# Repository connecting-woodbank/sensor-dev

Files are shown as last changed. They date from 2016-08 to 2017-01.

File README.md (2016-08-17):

README
======
The Connecting Woodbank project aims to create a wireless sensor network for monitoring growing conditions to reduce inefficiencies within small-scale agriculture.  It is comprised of a network of sensor nodes based around an Arduino board conected to a series of sensors and a short range radio.

Sensors
=======
The sensor nodes each contain sensors for measuring:
- soil temperature
- soil relative moisture
- air temperatue
- air relative humidity
- light level (Red, Green and Blue wavelengths)
- infra-red radiation

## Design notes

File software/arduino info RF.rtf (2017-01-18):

Arduino and NRF radio
General into: https://arduino-info.wikispaces.com/Nrf24L01-2.4GHz-HowTo#lib

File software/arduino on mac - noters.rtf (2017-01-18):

mac arduino notes
re-install CH340g driver for OSX Sierra from Winchiphead signed drivers for CH340-CH341, OS X 10.9 to macOS 10.12 (http://blog.sengotta.net/wp-content/uploads/2015/11/CH34x_Install_V1.3.zip)
select board: Arduino pro or mini pro
select processor: Atmega 328 (3.3V, 8 MHz)
select programmer: Arduino as ISP

Reading ports
- to find available ports:
ls /dev/cu.*
for arduino mini the response should include an entry such as /dev/cu.wchusbserialfd1420

- to open ports using terminal
- as per linux there are a variety of options available
screen - preferred option
to open a port e.g. wchusbserialfd1420 at 9600 baud from terminal use the following:
“screen /dev/tty.wchusbserialfd1420 9600”
to quit use Ctrl-a Ctrl-\

cu
to open a port e.g. wchusbserialfd1420 at 9600 baud from terminal use the following:
“sudo cu -l /dev/tty.wchusbserialfd1420 -s 9600”
to disconnect: “~.” followed by Enter

Terminal readers
- Coolterm is freely available and is a useful GUI interface for reading terminal outputs and saving to file
SSH keys
- useful guide to generating and using SSH keys on mac for github

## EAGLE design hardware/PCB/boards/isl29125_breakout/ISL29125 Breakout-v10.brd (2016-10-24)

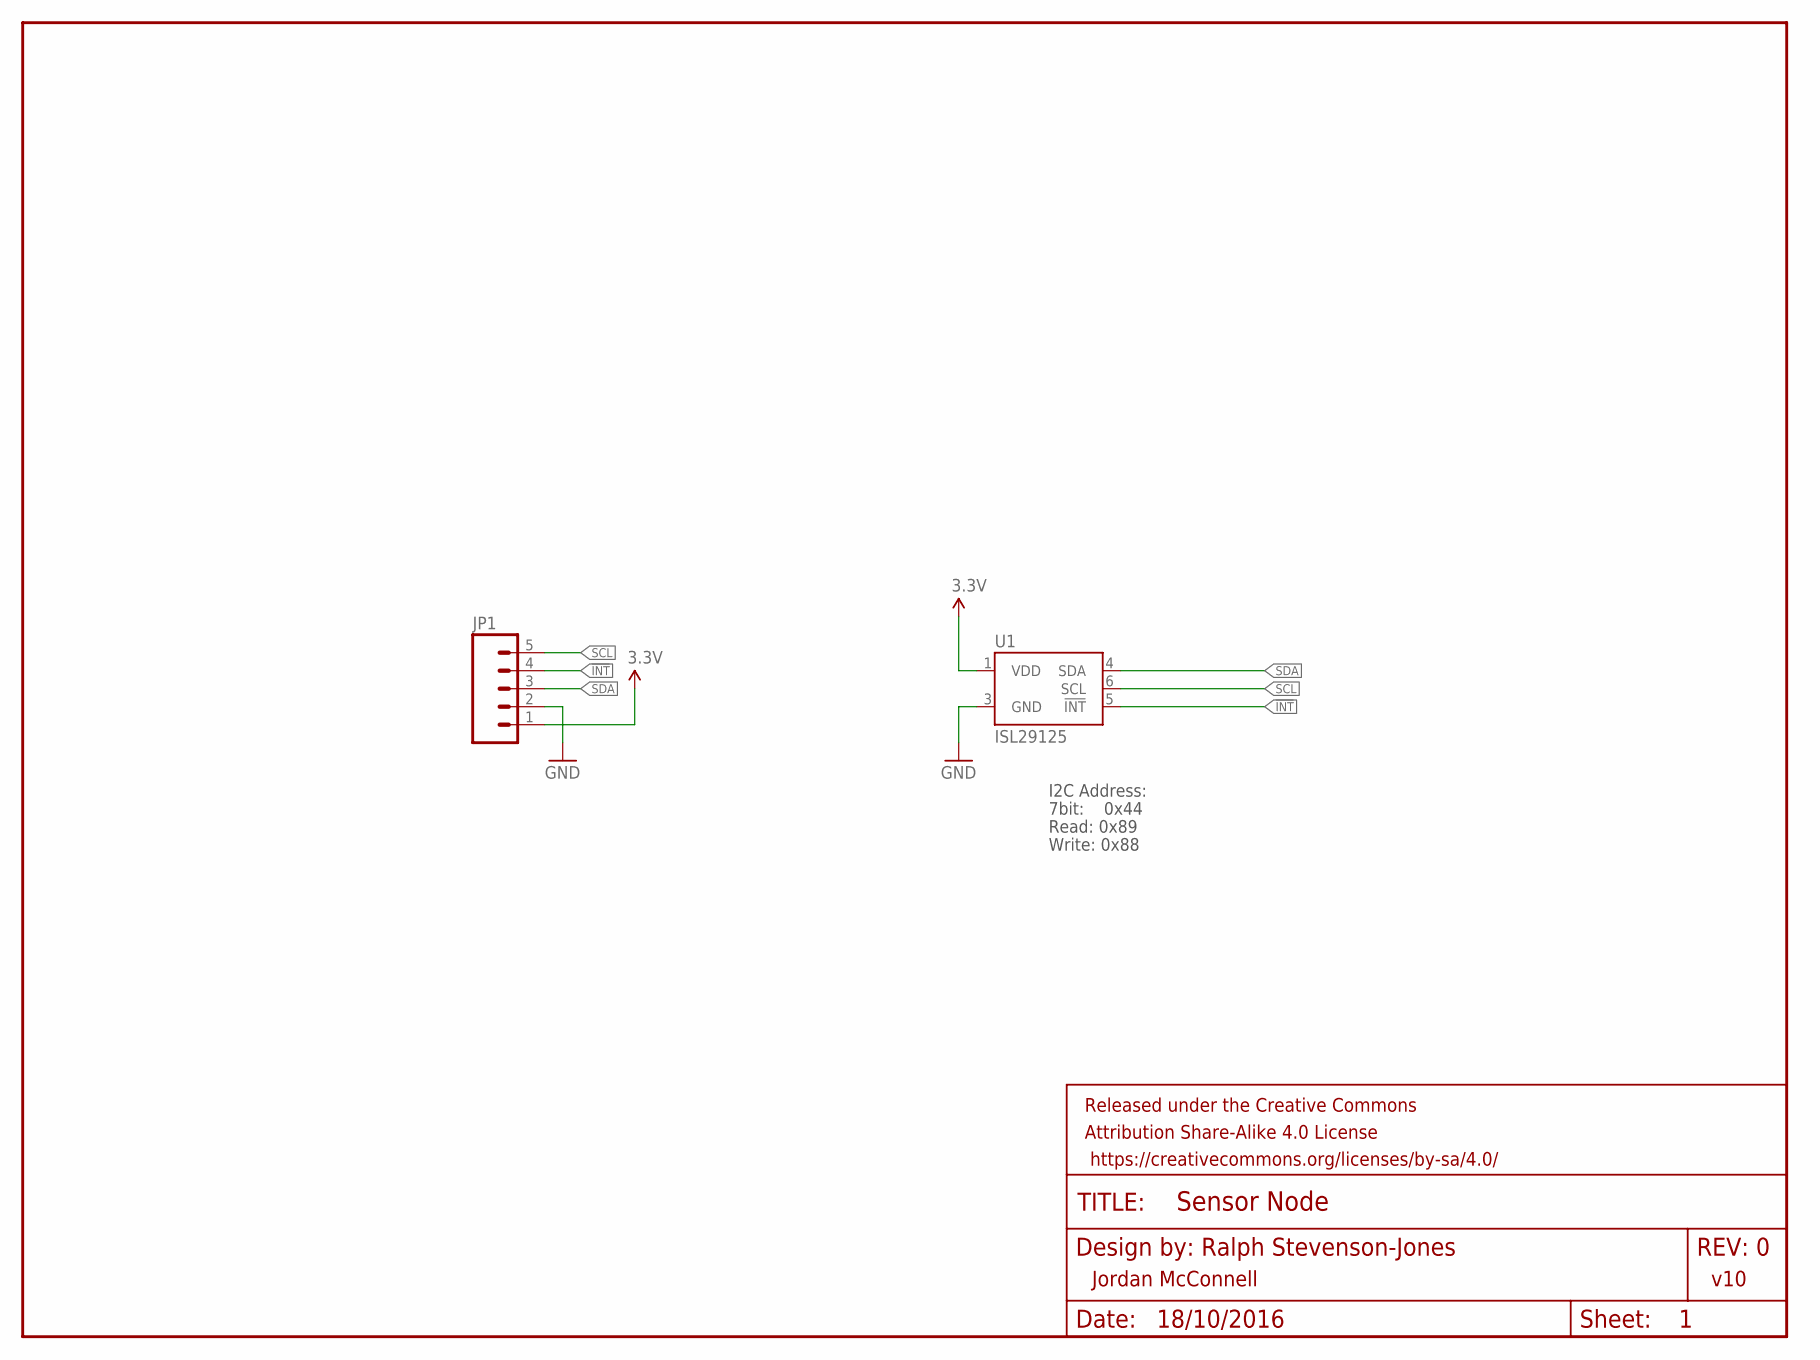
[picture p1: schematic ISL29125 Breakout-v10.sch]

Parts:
FRAME1: FRAME-LETTER; CREATIVE_COMMONS
JP1: M05PTH; 1X05
U1: ISL29125; ODFN-LD-6

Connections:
3.3V: JP1.1, U1.1 (VDD)
!INT: JP1.4, U1.5 (!INT)
GND: JP1.2, U1.3 (GND)
SCL: JP1.5, U1.6 (SCL)
SDA: JP1.3, U1.4 (SDA)

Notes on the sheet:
Jordan McConnell
v10
7bit: 0x44
I2C Address:
Read: 0x89
Write: 0x88

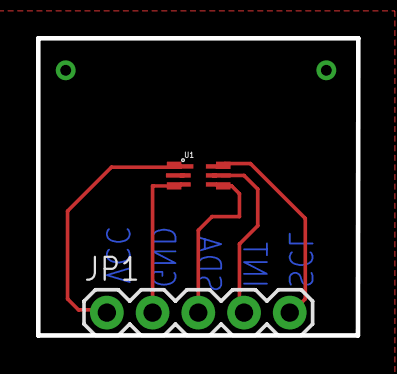
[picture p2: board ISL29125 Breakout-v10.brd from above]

Board: 2 copper layers, 17.8 x 16.5 mm, 3 parts (0 on the bottom side), 5 nets.

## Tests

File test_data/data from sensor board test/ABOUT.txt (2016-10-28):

Data format for bitscope files

- from DSO (??) application: [DSO guide](http://www.bitscope.com/software/dso/guide/2.5/?p=recorder)

trigger	stamp	channel	index	type	delay	factor	rate	count	data

- trigger: number identifying the tigger event
- stamp: timestamp identifying the time (of day) of the trigger
- channel: channel number (1-11)
- index: index identifying all records belonging to the same frame (seems to be the same within the same trigger event for channels 4-11 but different for 0,1)
- type: capture data type - encoded as digit e.g. 0
- delay: post-trigger delay applied (if any)
- factor: decimation/oversample factor applied (if any)
- rate: sample rate at which data was captured (Hz??)
- count: number of samples captured in the  record (total time is count/rate)
- data: data is formatted in rows per channel per trigger followed by entries from next trigger

DATA PROCESSING

- The easiest way to process the data is to manually select one specific trigger from the data e.g. in excel and then copy/paste transpose to another sheet.  The channels not used can then be imported using Matlab scripts.  An example data formate is shown.

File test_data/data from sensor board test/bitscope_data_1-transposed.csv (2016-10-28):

trigger | 1247 | 1247 | 1248 | 1248 | 1249 | 1249 | 1250 | 1250
stamp | 17:35:43 | 17:35:43 | 17:35:47 | 17:35:47 | 17:35:51 | 17:35:51 | 17:35:56 | 17:35:56
channel | 0 | 1 | 0 | 1 | 0 | 1 | 0 | 1
index | 1252 | 674 | 1253 | 675 | 1254 | 676 | 1255 | 677
type | 0 | 0 | 0 | 0 | 0 | 0 | 0 | 0
delay | -0.0003514 | -0.0003514 | -0.0003514 | -0.0003514 | -0.0003514 | -0.0003514 | -0.0003514 | -0.0003514
factor | 1 | 1 | 1 | 1 | 1 | 1 | 1 | 1
rate | 714290 | 714290 | 714290 | 714290 | 714290 | 714290 | 714290 | 714290
count | 1429 | 1429 | 1429 | 1429 | 1429 | 1429 | 1429 | 1429
data | 1.5812 | 1.5812 | 1.5812 | 1.6172 | 1.5812 | 1.5812 | 1.5812 | 1.5812
 | 1.5812 | 1.5992 | 1.5812 | 1.6172 | 1.5812 | 1.5812 | 1.5812 | 1.5992
 | 1.5812 | 1.6172 | 1.5812 | 1.6172 | 1.5812 | 1.5812 | 1.5812 | 1.6172
 | 1.5812 | 1.6172 | 1.5812 | 1.6172 | 1.5812 | 1.5812 | 1.5812 | 1.6172
 | 1.5812 | 1.6172 | 1.5812 | 1.6172 | 1.5812 | 1.5812 | 1.5812 | 1.6172
 | 1.5812 | 1.6172 | 1.5812 | 1.6172 | 1.5812 | 1.5812 | 1.5812 | 1.6172
 | 1.5812 | 1.6172 | 1.5812 | 1.6172 | 1.5812 | 1.5812 | 1.5812 | 1.6172
 | 1.5812 | 1.6172 | 1.5812 | 1.6172 | 1.5812 | 1.5812 | 1.5812 | 1.6172
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

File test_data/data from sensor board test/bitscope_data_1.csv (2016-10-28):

trigger | stamp | channel | index | type | delay | factor | rate | count | data
1246 | 17:35:38 | 1 | 673 | 0 | -0.0003514 | 1 | 714290 | 1429 | 1.6172 | 1.6172 | 1.6172 | 1.5992 | 1.5812 | 1.5992 | 1.6172 | 1.6172 | 1.6172 | 1.6172 | 1.6172 | 1.6172 | 1.6172 | 1.6172 | 1.6172 | 1.6172 | 1.6172 | 1.6172 | 1.6172 | 1.6172 | 1.6172 | 1.6172 | 1.6172 | 1.6172 | 1.6172 | 1.6172 | 1.6172 | 1.6172 | 1.6172 | 1.6172 | 1.6172 | 1.6172 | 1.6172 | 1.6172 | 1.6172 | 1.6172 | 1.6172 | 1.6172 | 1.6172 | 1.6172 | 1.6172 | 1.6172 | 1.6172 | 1.6172 | 1.6172 | 1.6172 | 1.6172 | 1.6172 | 1.6172 | 1.6172 | 1.6172
1246 | 17:35:38 | 4 | 461 | 0 | -0.0003514 | 1 | 714290 | 1429 | 0 | 0 | 0 | 0 | 0 | 0 | 0 | 0 | 0 | 0 | 0 | 0 | 0 | 0 | 0 | 0 | 0 | 0 | 0 | 0 | 0 | 0 | 0 | 0 | 0 | 0 | 0 | 0 | 0 | 0 | 0 | 0 | 0 | 0 | 0 | 0 | 0 | 0 | 0 | 0 | 0 | 0 | 0 | 0 | 0 | 0 | 0 | 0 | 0 | 0 | 0
1246 | 17:35:38 | 5 | 461 | 0 | -0.0003514 | 1 | 714290 | 1429 | 0 | 0 | 0 | 0 | 0 | 0 | 0 | 0 | 0 | 0 | 0 | 0 | 0 | 0 | 0 | 0 | 0 | 0 | 0 | 0 | 0 | 0 | 0 | 0 | 0 | 0 | 0 | 0 | 0 | 0 | 0 | 0 | 0 | 0 | 0 | 0 | 0 | 0 | 0 | 0 | 0 | 0 | 0 | 0 | 0 | 0 | 0 | 0 | 0 | 0 | 0
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

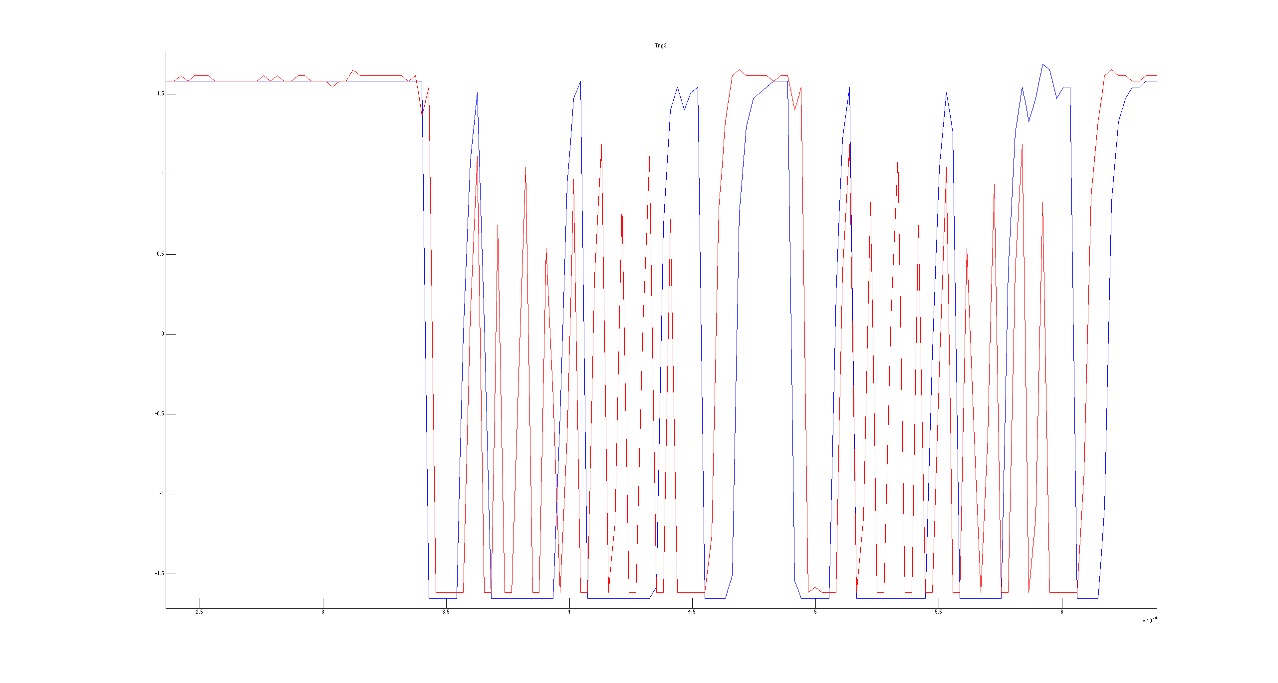
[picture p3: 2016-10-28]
test_data/data from sensor board test/i2c_plot.png

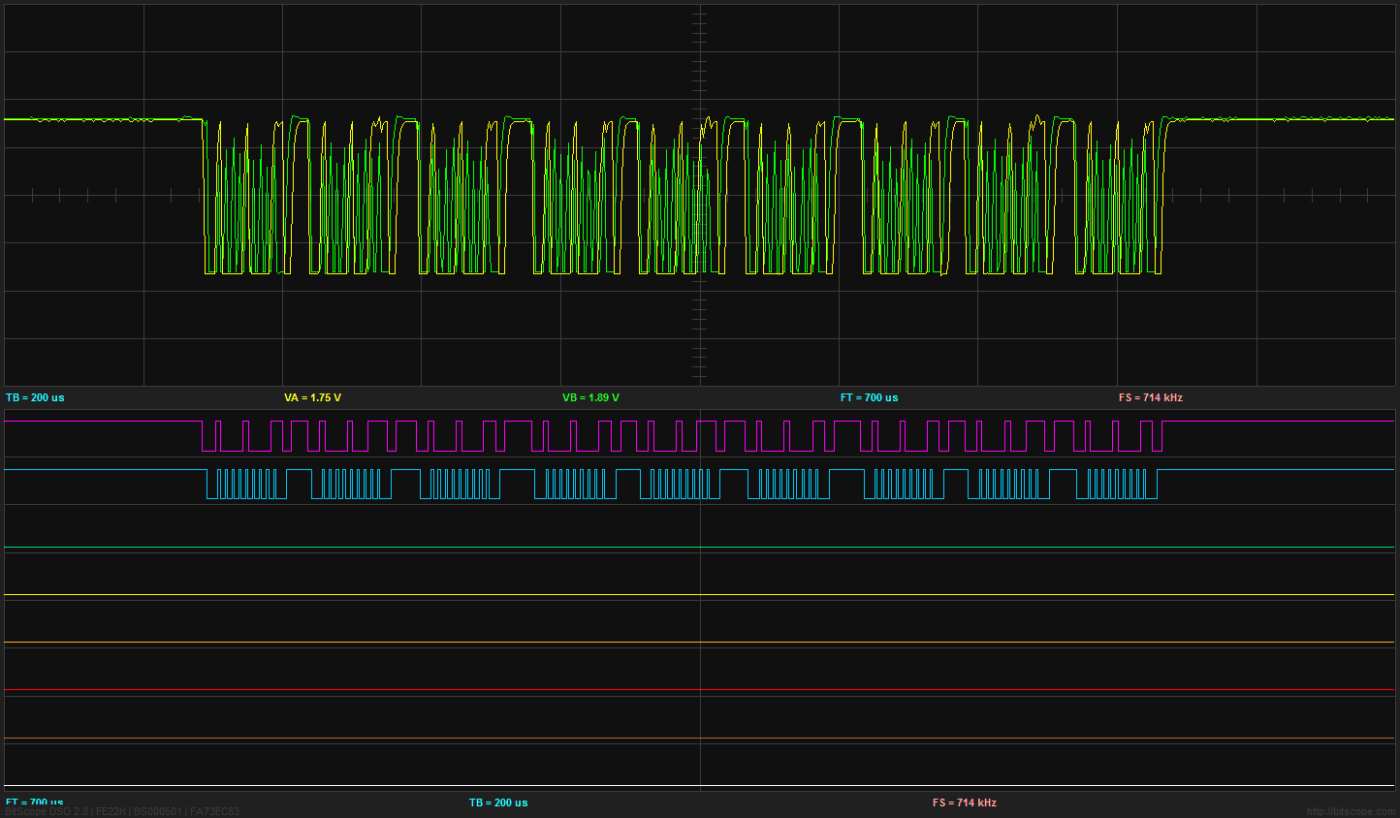
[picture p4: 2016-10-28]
test_data/data from sensor board test/BitScope.png

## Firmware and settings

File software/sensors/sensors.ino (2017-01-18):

// Sensors.ino

/* Sensor node fimrware August 2016
    version v1.0 - All sensors
    Andy Stevenson-Jones

    Arduino reads sensors and returns formatted data through the COM port
    Format: "Soil Moisture, Light (RGB), Soil Temperature, Air Temperature, Air Relative Humidity, IR Level"
*/


/* Pin allocations for Arduino
 *  Analog
  A0 - SoilMoisturePin: soil moisture analog output
  A4 - SDA (for I2C connecting RGB sensor)
  A5 - SCL (for I2C connecting RGB sensor)

 *  Digital
  D4 - SoilVccPin: power supply for soil moisture sensor
  D5 - DHT11_PIN: Air temperature/humidity digital output
  D6 - ONE_WIRE_BUS: Soil temperature digital output
*/

/*
 * VARIABLES
 * The values to send are:
 * SoilMoisture: unsinged int (0-1023)
 * red: signed int
 * green: unsigned int
 * blue: unsigned int
 * SoilTemp: signed char
 * AirTemp: signed char
 * AirHumidity: unsigned char
 */

 /*
  * MESSAGE STRUCTURE
      msg[0] = SoilMoisture UB
      msg[1] = SoilMoisture LB;
      msg[2] = red UB
      msg[3] = red LB
      msg[4] = green UB
      msg[5] = green LB
      msg[6] = blue UB
      msg[7] = blue LB
      msg[8] = SoilTemp
      msg[9] = AirTemp 
      msg[10] = AirHumidity
      msg[11] = photoIR UB
      msg[12] = photoIR LB
  */




// Libraries
#include <Wire.h>
#include <SparkFunISL29125.h>
#include <dht.h>
#include <OneWire.h>
#include <DallasTemperature.h>

// GENERAL DEFITIONS
// is it an arduino mini? - used to set clock rates
#define BAUD_RATE 9600

// Define pins for sensors
// Digital
#define DHT11_PIN 5   // DHT digital pin
#define ONE_WIRE_BUS 6  // Dallas temperature sensor digital pin

#define SoilMoisturePin  0  // analog read from soil moisture sensor, analog
#define SoilVccPin  4  // digital pin used as Vcc.  Sensor is connected from here to GND to reduce degredation of sensor
#define IRPin  1  // analog pin from IR photosensor
#define IRVccPin  3 // Vcc to IR photosensor


// DEFINE OBJECTS

// DHT11, air temperature/humidity
dht DHT;  // declare sensor object

// Dallas temperature sensor (soil)
OneWire oneWire(ONE_WIRE_BUS); // Setup a oneWire instance to communicate with any OneWire devices (not just Maxim/Dallas temperature ICs)
DallasTemperature sensors(&oneWire); // Pass our oneWire reference to Dallas Temperature.
DeviceAddress soilThermometer; // arrays to hold device address

// ISL29125: RGB photosensor
SFE_ISL29125 RGB_sensor; // Declare sensor object


// begin setup
void setup() {  
  // general setup
  Serial.begin(BAUD_RATE);
  Serial.println("Serial Comms setup.");

  // ISL29125 RGB PHOTOSENSOR

  // Initialize the ISL29125 with simple configuration so it starts sampling
  if (RGB_sensor.init())
  {
    Serial.println("Light sensor Initialization Successful\n\r");
  }


  // DALLAS T/RH SENSOR
  Serial.println("Initiliase Dallas T sensor");
  Serial.println("Dallas Temperature IC Control Library Demo");
  // locate devices on the bus
  Serial.print("Locating devices...");
  sensors.begin();
  Serial.print("Found ");
  Serial.print(sensors.getDeviceCount(), DEC);
  Serial.println(" devices.");

  // report parasite power requirements
  Serial.print("Parasite power is: ");
  if (sensors.isParasitePowerMode()) Serial.println("ON");
  else Serial.println("OFF");

  // Search for devices on the bus and assign based on an index.  Only one sensor shouldbe found here but more may be used.
  if (!sensors.getAddress(soilThermometer, 0)) Serial.println("Unable to find address for soil temperature sensor");

  // show the addresses found on the bus
  Serial.print("Soil temperature sensor address: ");
  printAddress(soilThermometer);
  Serial.println();

  // set the resolution to 9 bit (Each Dallas/Maxim device is capable of several different resolutions)
  sensors.setResolution(soilThermometer, 9);
  Serial.print("Soil temperature resolution: ");
  Serial.print(sensors.getResolution(soilThermometer), DEC);
  Serial.println();


  // soil moisture
  pinMode(SoilVccPin, OUTPUT);  // Vcc pin for soil moisture sensor
  digitalWrite(SoilVccPin, LOW);   // disable sensor

  // IR phototransistor
  pinMode(IRVccPin, OUTPUT);  // set to out
  digitalWrite(IRVccPin, LOW);  // make sure it's off


  // COMPLETE SETUP
  Serial.println("Node setup complete.");
  Serial.println("--------------------------------------------");
  Serial.println();
  Serial.println("Soil Moisture, Light (RGB), Soil Temperature, Air Temperature, Air Relative Humidity, IR Level, DHT checksum error");
  delay(2000);
}

// BEGIN LOOP
void loop() {

  // SOIL MOISTURE
  digitalWrite(SoilVccPin, HIGH);   // enable sensor
  delay(50);  // allow power to settle
  unsigned int SoilMoisture = 1023 - (analogRead(SoilMoisturePin)); // read analog voltage then negate so that open circuit -> 0, short circtuit -> 1023
  digitalWrite(SoilVccPin, LOW);   // disable sensor


  // RGB PHOTOSENSOR
  // Read sensor values (16 bit integers)
  unsigned int red = RGB_sensor.readRed();
  unsigned int green = RGB_sensor.readGreen();
  unsigned int blue = RGB_sensor.readBlue();


  // SOIL TEMPPERATURE
  sensors.requestTemperatures(); // Send the command to get temperatures
  signed char SoilTemp = sensors.getTempC(soilThermometer);


  // DHT AIR T/RH SENSOR
  int chk = DHT.read11(DHT11_PIN);
  int dht_checksum_error=0; // variable to hold error codes
  switch (chk)
  {
    case DHTLIB_OK:
      //               Serial.print("OK,\t");
      break;
    case DHTLIB_ERROR_CHECKSUM:
      //Serial.print("Checksum error,\t");
      dht_checksum_error |= 0x01;
      break;
    case DHTLIB_ERROR_TIMEOUT:
      //Serial.print("Time out error,\t");
      dht_checksum_error |= 0x02;
      break;
    case DHTLIB_ERROR_CONNECT:
      //Serial.print("Connect error,\t");
      dht_checksum_error |= 0x04;
      break;
    case DHTLIB_ERROR_ACK_L:
      //Serial.print("Ack Low error,\t");
      dht_checksum_error |= 0x08;
      break;
    case DHTLIB_ERROR_ACK_H:
      //Serial.print("Ack High error,\t");
      dht_checksum_error |= 0x10;
      break;
    default:
      //Serial.print("Unknown error,\t");
      dht_checksum_error |= 0x80;
      break;
  }
  // display data
  signed char AirTemp = DHT.temperature;
  unsigned char AirHumidity = DHT.humidity;


  //IR PHOTOSENSOR
  digitalWrite(IRVccPin, HIGH);   // enable sensor
  int photoIR = analogRead(IRPin); // read IR level
  digitalWrite(IRVccPin, LOW);   // disable sensor


  // construct message
  unsigned char msg[13];
  msg[0] = (SoilMoisture >> 8) & 0xFF;
  msg[1] = SoilMoisture & 0xFF;
  msg[2] = (red >> 8) & 0xFF;
  msg[3] = red & 0xFF;
  msg[4] = (green >> 8) & 0xFF;
  msg[5] = green & 0xFF;
  msg[6] = (blue >> 8) & 0xFF;
  msg[7] = blue & 0xFF;
  msg[8] = SoilTemp & 0xFF;
  msg[9] = AirTemp & 0xFF;
  msg[10] = AirHumidity & 0xFF;
  msg[11] = (photoIR >> 8) & 0xFF;
  msg[12] = photoIR & 0xFF;

  // display msg
  /*
  for (int i=0; i<sizeof(msg); i++)
  {
    Serial.print(msg[i], HEX);
    Serial.print(", ");
  }
  Serial.println();
*/

  // DISPLAY data
  Serial.print(SoilMoisture, DEC); // soil moisture level
  Serial.print(", ");
  Serial.print(red, DEC); // RGB: RED
  Serial.print(", ");
  Serial.print(green, DEC); // RGB: GREEN
  Serial.print(", ");
  Serial.print(blue, DEC); // RGB: BLUE
  Serial.print(", ");
  Serial.print(SoilTemp, DEC);  // soil temperature
  Serial.print(", ");
  Serial.print(AirTemp, DEC); // Air temperature
  Serial.print(", ");
  Serial.print(AirHumidity, DEC); // Air Humidity
  Serial.print(", ");
  Serial.print(photoIR);  // IR level
  Serial.print(", ");
  Serial.print(dht_checksum_error);  // DHT checksum error


  // finish
  Serial.println();
  delay(2000);


}

// FUNCTION DEFINTIONS

// soil temperature function to print the temperature for a device
void printTemperature(DeviceAddress deviceAddress)
{
  // method 1 - slower
  //Serial.print("Temp C: ");
  //Serial.print(sensors.getTempC(deviceAddress));
  //Serial.print(" Temp F: ");
  //Serial.print(sensors.getTempF(deviceAddress)); // Makes a second call to getTempC and then converts to Fahrenheit

  // method 2 - faster
  float tempC = sensors.getTempC(deviceAddress);
  Serial.print(tempC);
  Serial.print(", ");
  //  Serial.print(" Temp F: ");
  //  Serial.println(DallasTemperature::toFahrenheit(tempC)); // Converts tempC to Fahrenheit
}

// function to print a device address of soil temperature sensor
void printAddress(DeviceAddress deviceAddress)
{
  for (uint8_t i = 0; i < 8; i++)
  {
    if (deviceAddress[i] < 16) Serial.print("0");
    Serial.print(deviceAddress[i], HEX);
  }
}

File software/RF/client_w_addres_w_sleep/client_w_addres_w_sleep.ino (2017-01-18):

/*
 * Read sensors and transmit data over radio
 * 
 * Message format
 * Length: 20 bytes
 * format:
  msg[0] = (tx_count>>8) & 0xFF;
  msg[1] = tx_count & 0xFF;
  msg[2] = (red >> 8) & 0xFF;
  msg[3] = red & 0xFF;
  msg[4] = (green >> 8) & 0xFF;
  msg[5] = green & 0xFF;
  msg[6] = (blue >> 8) & 0xFF;
  msg[7] = blue & 0xFF;
  msg[8] = SoilMoisture & 0xFF;
  msg[9] = SoilTemp & 0xFF;
  msg[10] = AirTemp & 0xFF;
  msg[11] = AirHumidity & 0xFF;
  msg[12] = (dht_checksum_error>>8) & 0xFF;
  msg[13] = dht_checksum_error & 0xFF;

 Pin allocations for Arduino
 *  Analog
  A0 - SoilMoisturePin: soil moisture analog output
  A4 - SDA (for I2C connecting RGB sensor)
  A5 - SCL (for I2C connecting RGB sensor)

 *  Digital
  D4 - SoilVccPin: power supply for soil moisture sensor
  D5 - DHT11_PIN: Air temperature/humidity digital output
  D6 - ONE_WIRE_BUS: Soil temperature digital output

 * VARIABLES
 * The values to send are:
 * SoilMoisture: unsinged int (0-1023)
 * red: signed int
 * green: unsigned int
 * blue: unsigned int
 * SoilTemp: signed char
 * AirTemp: signed char
 * AirHumidity: unsigned char
 */

#include <LowPower.h>
#include <RHReliableDatagram.h>
#include <RH_NRF24.h>
#include <SPI.h>
#include <Wire.h>
#include <dht.h>
#include <SparkFunISL29125.h>
#include <OneWire.h>
#include <DallasTemperature.h>

// SENSORS
// DHT11
#define DHT11_PIN 5
dht DHT;
// ISL29125: RGB photosensor
SFE_ISL29125 RGB_sensor; // Declare sensor object
// Dalla temperature sensor
#define ONE_WIRE_BUS 6  // Dallas temperature sensor digital pin
OneWire oneWire(ONE_WIRE_BUS); // Setup a oneWire instance to communicate with any OneWire devices (not just Maxim/Dallas temperature ICs)
DallasTemperature sensors(&oneWire); // Pass our oneWire reference to Dallas Temperature.
DeviceAddress soilThermometer; // arrays to hold device address
// Soil moisture sensor
#define SoilMoisturePin  0  // analog read from soil moisture sensor, analog
#define SoilVccPin  4  // digital pin used as Vcc.  Sensor is connected from here to GND to reduce degredation of sensor


//RF
#define CLIENT_ADDRESS 2 //self address
#define msg_length 20 // length of message
uint8_t SERVER_ADDRESS = 1; //address of the server node
uint8_t buf[RH_NRF24_MAX_MESSAGE_LEN];

// declare variables
signed char AirTemp=0;
unsigned char AirHumidity=0;
unsigned int red=0;
unsigned int blue=0;
unsigned int green=0;
signed char SoilTemp=0;
unsigned int SoilMoisture=0;
unsigned char msg[msg_length];
unsigned int tx_count=0;
int count=0;

// Single instance of the radio driver
 RH_NRF24 driver(7, 8);   // For RFM73 on Anarduino Mini

// Class to manage msg delivery and receipt, using the driver declared above
RHReliableDatagram manager(driver, CLIENT_ADDRESS);

void setup() 
{
  // initalise serial
  Serial.begin(9600);
  Serial.println("Serial setup complete");
  if(!clientInit())//initiate the RF client
    Serial.print("RF init Failed!");
    
  // initialise sensors
  senseInit();
  
  // Finish setup
  Serial.println("Setup complete");
}



void loop()
{
  count++;
  //chech if the time slept is enough to call back
  if (count==CLIENT_ADDRESS*1){
   delay(50);
   //sense();
// DHT AIR T/RH SENSOR
  int chk = DHT.read11(DHT11_PIN);
  int dht_checksum_error=0x00; // variable to hold error codes
  switch (chk)
  {
    case DHTLIB_OK:
      //               Serial.print("OK,\t");
      break;
    case DHTLIB_ERROR_CHECKSUM:
      //Serial.print("Checksum error,\t");
      dht_checksum_error |= 0x01;
      break;
    case DHTLIB_ERROR_TIMEOUT:
      //Serial.print("Time out error,\t");
      dht_checksum_error |= 0x02;
      break;
    case DHTLIB_ERROR_CONNECT:
      //Serial.print("Connect error,\t");
      dht_checksum_error |= 0x04;
      break;
    case DHTLIB_ERROR_ACK_L:
      //Serial.print("Ack Low error,\t");
      dht_checksum_error |= 0x08;
      break;
    case DHTLIB_ERROR_ACK_H:
      //Serial.print("Ack High error,\t");
      dht_checksum_error |= 0x10;
      break;
    default:
      //Serial.print("Unknown error,\t");
      dht_checksum_error |= 0x80;
      break;
  }
  // display data
  AirTemp = DHT.temperature;
  AirHumidity = DHT.humidity;
  //AirTemp = 0x28;
  //Serial.println("T/RH measured");

  // Read PHOTOSENSOR values (16 bit integers)
  red = RGB_sensor.readRed();
  green = RGB_sensor.readGreen();
  blue = RGB_sensor.readBlue();

    // SOIL TEMPPERATURE
  sensors.requestTemperatures(); // Send the command to get temperatures
  SoilTemp = sensors.getTempC(soilThermometer);

  // SOIL MOISTURE
  digitalWrite(SoilVccPin, HIGH);   // enable sensor
  delay(50);  // allow power to settle
  unsigned int SoilMoisture = (1023 - (analogRead(SoilMoisturePin)))>>2; // read analog voltage then negate so that open circuit -> 0, short circtuit -> 1023.  Convert to 8 bits
  digitalWrite(SoilVccPin, LOW);   // disable sensor

  // increment tx count
   tx_count++;
   if (tx_count >= 65535){tx_count = 0;}

  // Construct msg
  msg[0] = (tx_count>>8) & 0xFF;
  msg[1] = tx_count & 0xFF;
  msg[2] = (red >> 8) & 0xFF;
  msg[3] = red & 0xFF;
  msg[4] = (green >> 8) & 0xFF;
  msg[5] = green & 0xFF;
  msg[6] = (blue >> 8) & 0xFF;
  msg[7] = blue & 0xFF;
  msg[8] = SoilMoisture & 0xFF;
  msg[9] = SoilTemp & 0xFF;
  msg[10] = AirTemp & 0xFF;
  msg[11] = AirHumidity & 0xFF;
  msg[12] = (dht_checksum_error>>8) & 0xFF;
  msg[13] = dht_checksum_error & 0xFF;

  
//  for (int i=0; i<sizeof(msg); i++){Serial.print(msg[i],HEX);Serial.print(",");}
//  Serial.print("\r\n");
//  Serial.println(msg);
 
   sendToServer(msg,sizeof(msg));
   count=0;
  delay(50);//small delay to allow all operations before sleeping again
  // Sleep with ADC module and BOD module off
  LowPower.powerDown(SLEEP_8S, ADC_OFF, BOD_OFF);
  }
}

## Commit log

2016-08-17 Added sensor code
2016-08-17 Format code
    sensors.ino updated and formatted of clarity
2016-08-17 separated serial print
    separated serial print functions from the sensor read functions. This
    is to allow values to be sent through the radio as (multiple) 8-bit
    values.
2016-08-19 Updated for compatibility with Mini
    - defined baud rate using macro
    - included #ifdef condition to set clock rate for mini to support 8MHz
    cock rate on 3.3V mini
2016-10-24 Added ISL29125 shield
    - restructured file layout (added hardware/software folders)
    - added ISL29125 board
    - amended pads for ease of soldering
    [ISL29125 Breakout-v10.brd, ISL29125 Breakout-v10.sch]
2016-10-26 Test mode
    test function of sensors within node without reading values
    (initilisation only)
2016-10-28 Test I2 C line
    The I2C line was tested with the new PCB and it was found that the I2C
    bus would not return data. Test data is added and analysed.
    TO DO
    - amend clock rate of the I2C bus. There appears to be extra
    capacitance in the line. Attempt to amend this by reducing clock rate
    of the I2C bus. At present the arduino is using the default rate of
    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
    [bitscope_data_1-transposed.csv, bitscope_data_1.csv]
2016-10-28 Updated sensors.ino
    - deleted test function print
2016-11-01 added sensor test figure
    - tesing I2C bus illustration of error source
2017-01-12 added notes on using arduino on linux
2017-01-12 added mac notes for arudion re. drivers, serial read
2017-01-18 updated mac arduino guide
2017-01-18 added additinal arduino libraries
2017-01-18 updated sensors standalone firmware

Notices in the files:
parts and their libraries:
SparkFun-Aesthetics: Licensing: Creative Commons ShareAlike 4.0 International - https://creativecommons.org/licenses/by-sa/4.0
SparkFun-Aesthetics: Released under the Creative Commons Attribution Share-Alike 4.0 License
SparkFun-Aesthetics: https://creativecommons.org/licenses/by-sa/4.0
